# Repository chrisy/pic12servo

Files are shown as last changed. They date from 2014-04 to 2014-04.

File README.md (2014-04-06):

pic12servo
==========

This is a simple program to drive a hobby servo with a PIC12F683. It was
prepared using the MPLAB X IDE and the xc8 compiler.

The code sets up an analog-to-digital convertor input on pin 7 and
a PWM output on pin 5. It also sets up pulse outputs on pins 2 and 3
to allow us to measure the loop timing on an oscilloscope. The output
on pin 2 should be slow enough for a blinking LED.

The program loops reading the 10-bit value from the ADC and sets the
duty cycle of the PWM to a value derived from it.

The usable range for most servos requires a pulse length of between
about 1ms to 2ms (which represents the full range of motion for the
servo) with an overall pulse rate greater than 50Hz. This program
configures the PWM output to something close to 61Hz and calculates
the duty cycle value to correspond to a pulse of between about 1 and
2ms.

By hooking up a simple 10K ohm linear potentiometer wiper to pin 7,
with the pot ends across 0v and Vdd (the positive power to the PIC,
for example 5v) then the relative position of the pot will represent
the relative position of the servo motor across its full range.

Suitable hardware designs to facilitate this are in the hardware
directory.

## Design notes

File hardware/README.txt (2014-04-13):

The ServoDriver hardware
========================

servodriver.sch and servodriver.brd are Eagle diagrams.

servodriver.*.tap are G-Code CAM scripts generated using gcode-pcb.ulp.

Bill of Materials
=================

IC1		PIC12F683P (programmed, with 8 pin IC socket)
IC2		7805

R1		10K Pot
R2		Link
R3		620R
R4		620R

C1		0.1uF
C2		0.1uF
C3		0.1uF
C4		100uF electrolytic (25V or higher)
C5		10uF electrolytic (10V or higher)
C6		0.1uF

D1		1N4004

LED1	3mm red LED
LED2	3mm red LED

JP1		2-way Screw terminal
JP2		3-way 0.1" pitch pin header

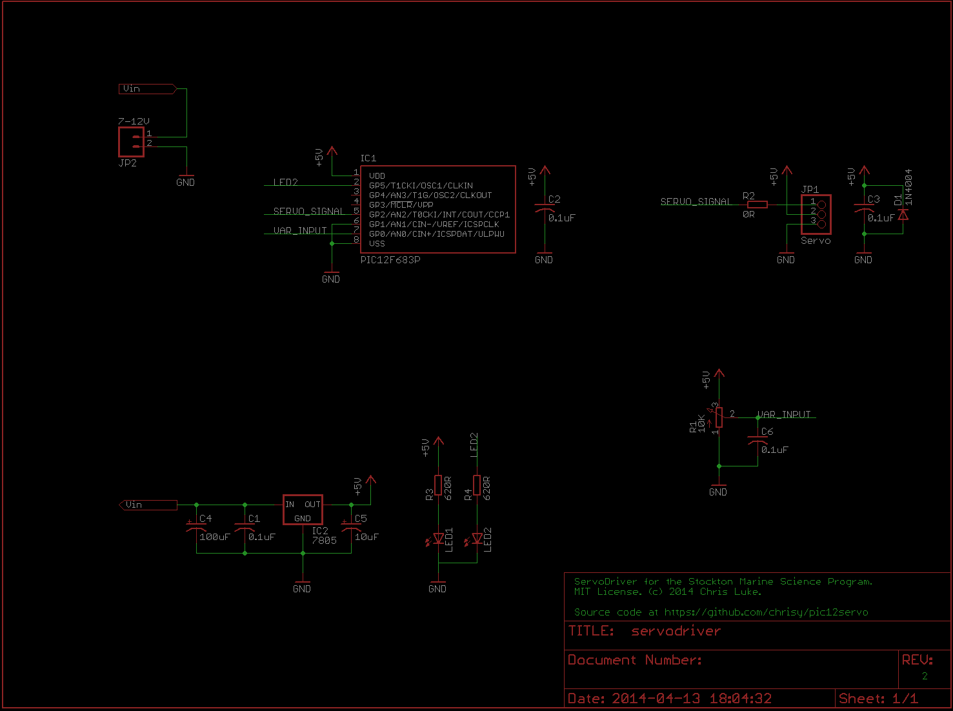
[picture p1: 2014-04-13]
hardware/servodriver-schematic.png

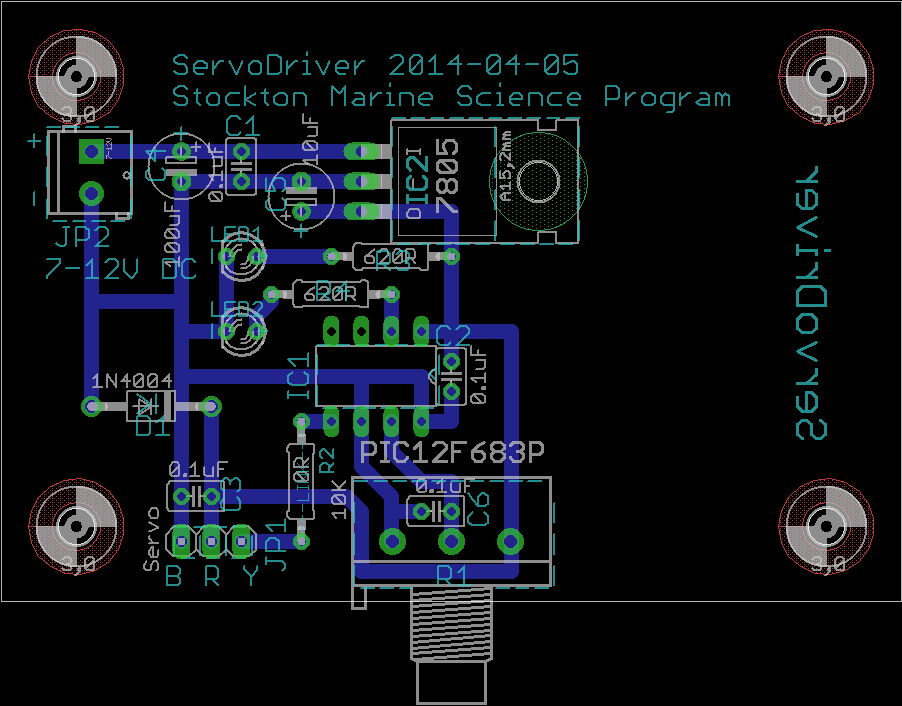
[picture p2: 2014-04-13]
hardware/servodriver-board.png

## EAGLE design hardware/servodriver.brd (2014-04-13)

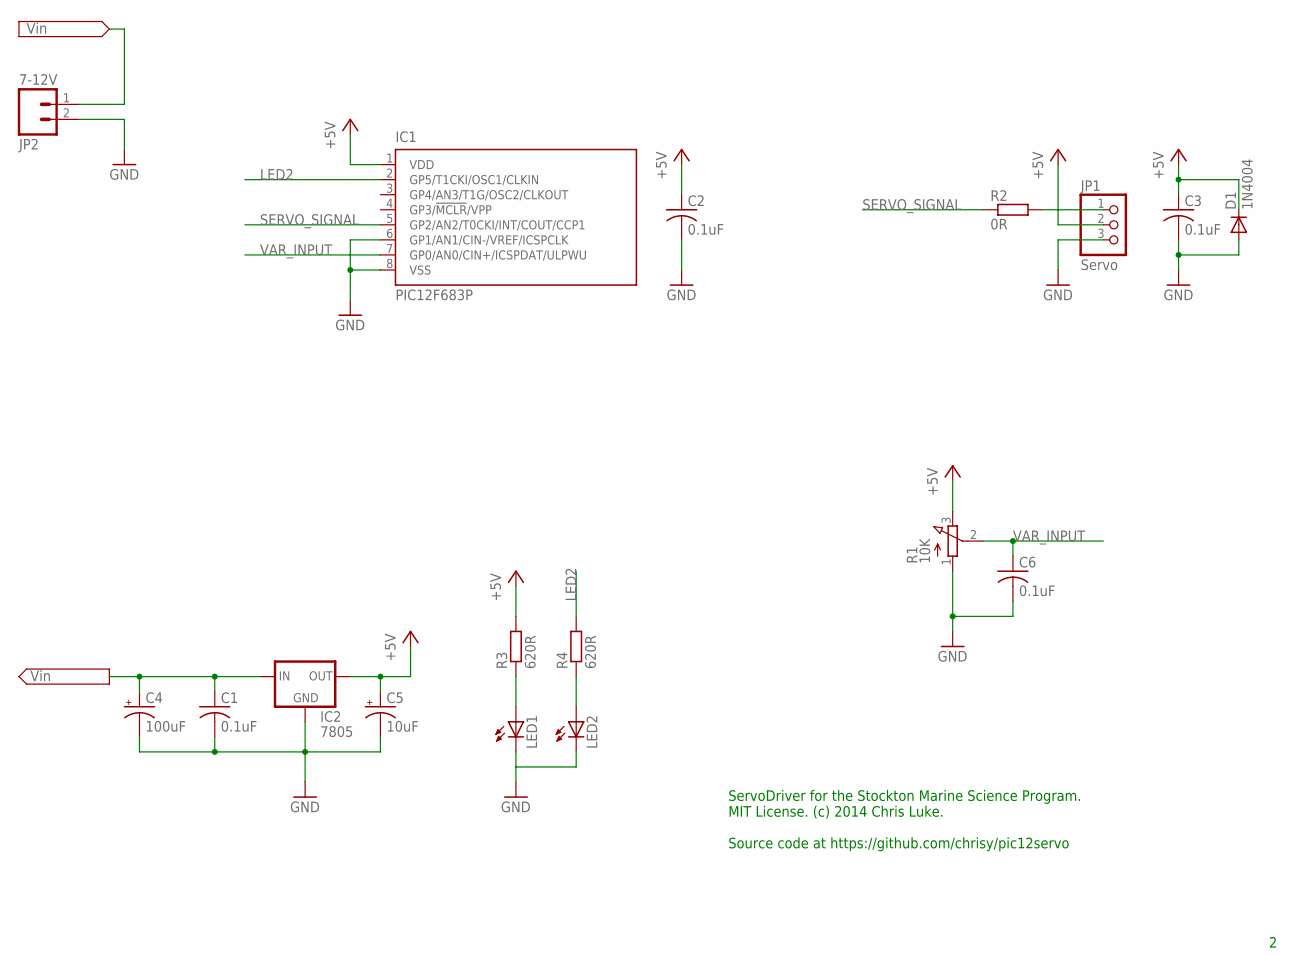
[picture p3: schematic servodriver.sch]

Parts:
C1, C2, C3, C6: 0.1uF; C025-025X050
C4: 100uF; E2,5-6
C5: 10uF; E2,5-6
D1: 1N4004; DO41-10
IC1: PIC12F683P; DIL8
IC2: 7805; 78XXL
JP1: Servo; 1X03
JP2: 7-12V; SCREWTERMINAL-3.5MM-2
LED1, LED2: LED3MM
R1: 10K; 3RP/1610N
R2: 0R; 0207/10
R3, R4: 620R; 0207/10

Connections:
+5V: C2.1, C3.1, C5.+, D1.C, IC1.1 (VDD), IC2.OUT, JP1.2, R1.3 (E), R3.2
GND: C1.2, C2.2, C3.2, C4.-, C5.-, C6.2, D1.A, IC1.6 (GP1/AN1/CIN-/VREF/ICSPCLK), IC1.8 (VSS), IC2.GND, JP1.3, JP2.2, LED1.K (C), LED2.K (C), R1.1 (A)
LED2: IC1.2 (GP5/T1CKI/OSC1/CLKIN), R4.2
unnamed: JP1.1, R2.2
unnamed: LED1.A, R3.1
unnamed: LED2.A, R4.1
SERVO_SIGNAL: IC1.5 (GP2/AN2/T0CKI/INT/COUT/CCP1), R2.1
VAR_INPUT: C6.1, IC1.7 (GP0/AN0/CIN+/ICSPDAT/ULPWU), R1.2 (S)
VIN: C1.1, C4.+, IC2.IN, JP2.1

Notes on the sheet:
ServoDriver for the Stockton Marine Science Program. MIT License. (c) 2014 Chris Luke. Source code at https://github.com/chrisy/pic12servo

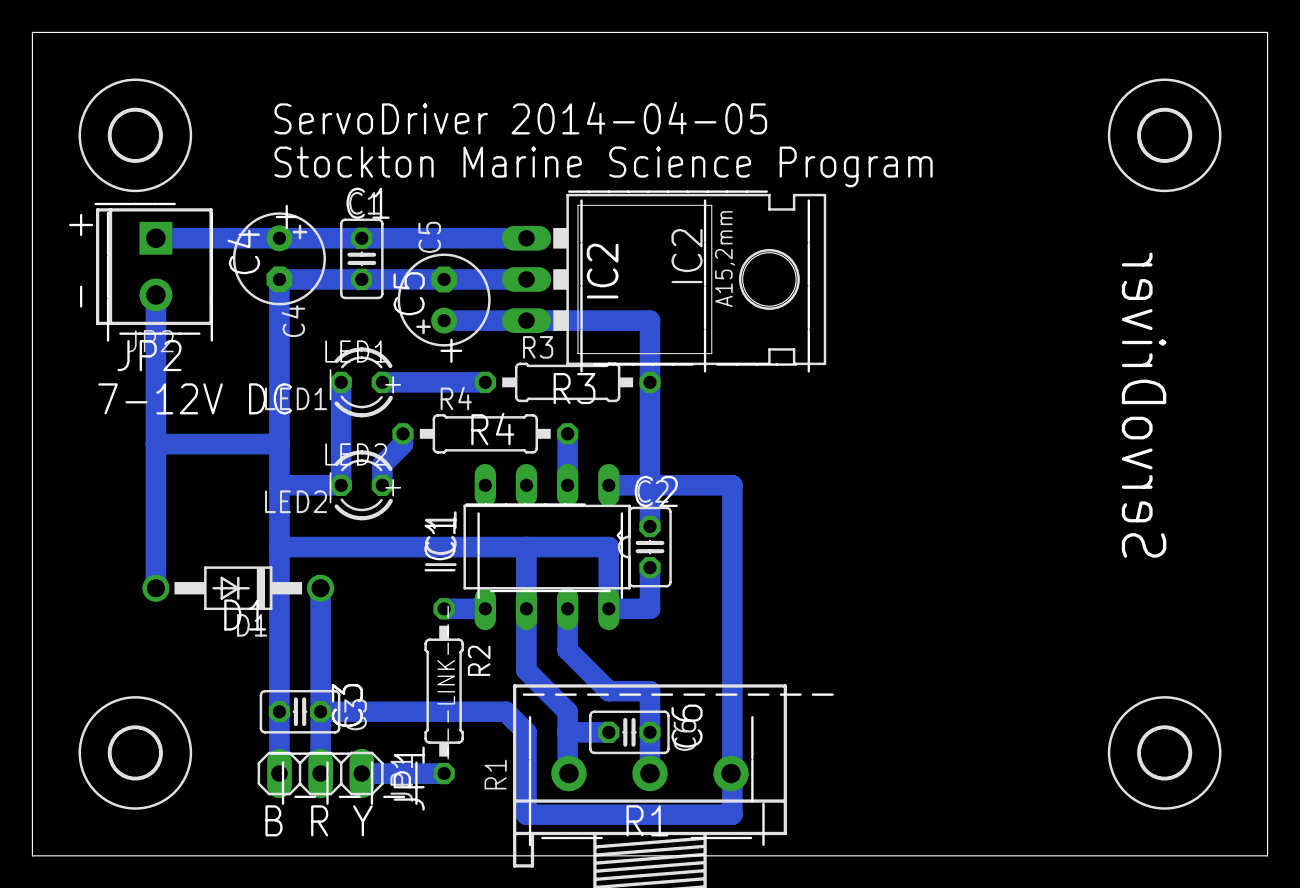
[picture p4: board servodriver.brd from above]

Board: 2 copper layers, 76.2 x 50.8 mm, 21 parts (0 on the bottom side), 9 nets.

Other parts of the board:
U$1, U$2, U$3, U$4: 3,0

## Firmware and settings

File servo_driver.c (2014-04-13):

/* 
 * File:    servo_driver.c
 * Author:  Chris Luke <chrisy@flirble.org>
 * License: MIT (c) 2014 Chris Luke
 */

#include "servo_driver.h"
#include "config.h"
#include <xc.h>

/* Initialize the hardware
 * GP0 is the analog input. Pin 7.
 * GP1 is unused though the board connects it to 0v for shielding. Pin 6.
 * GP2 is the PWM outut. Pin 5.
 * GP3 is unused. Pin 4.
 * GP4 is a loop-interval toggle output. Pin 3.
 * GP5 is an LED output. Pin 2.
 */
void init(void)
{
    OSCCONbits.IRCF = SET_IRCF; /* Set the clock speed */
    WDTCON = 0; /* Make sure watchdog is disabled */
    T1CON = 0; /* Make sure unused timers are off */

    di(); /* No need for interrupts */

    /* Setup the I/O */
    OPTION_REG = 0; /* Pullups via WPU */
    WPU = 0; /* No pullups to start with */
    GPIO = 0; /* Make sure all outputs are low */
    CMCON0 = 7; /* Disable the comparator */
    CMCON1 = 0;
    TRISIO = 0b001111; /* 4,5=out, 0,1,2,3=in */

    /* Setup ADC */
    ADCON0bits.ADFM = 1; /* right justified result */
    ADCON0bits.VCFG = 0; /* Use Vdd as Vref */
    ADCON0bits.CHS = 0; /* Select channel 0 */
    GO_DONE = 0; /* Make sure this is cleared */
    ANSELbits.ANS = 1; /* Only channel 0 is enabled */
    ANSELbits.ADCS = 0b111; /* Use internal RC oscilator */
    ADON = 1; /* Emable the ADC */

    /* Setup PWM */
    TRISIO2 = 1; /* Disable output on this pin for now */
    PR2 = SET_PR2; /* Set the PWM period (we aim for ~20ms, see config.h)  */
    CCP1CONbits.CCP1M = 0b1100; /* PWM mode */
    CCPR1L = 0; /* Reset PWM output to 0 */
    CCP1CONbits.DC1B = 0;

    /* Set the timer up for PWM operation */
    TMR2IF = 0; /* Make sure this is clear */
    T2CONbits.T2CKPS = 2; /* Timer 2 16:1 prescale */
    T2CONbits.TMR2ON = 1; /* TImer 2 on */

    while(!TMR2IF) { /* Wait for Timer 2 */
        continue;
    }
    TRISIO2 = 0; /* Set the pin as output */

    /* We have an LED on GP5 */
    TRISIO5 = 0;
    WPU5 = 0; /* Disable any pullup */

    /* And we will toggle GP4 for each iteration of the loop;
     * There's no real reason for this, other than we can
     * hook it up to an oscilloscope to time the loop
     * interval */
    TRISIO4 = 0;
    WPU4 = 0; /* Disable any pullup */

    /* Let it all settle */
    __delay_ms(10);
}

/*
 * Simple loop to read ADC value and set PWM duty
 * to the same value as a ratio of its range.
 */
int main(int argc, char **argv)
{
    unsigned int period, count;
    char o4, o5;

    /* Initialize the hardware */
    init();

    /* Calculate the PWM period from what we set PR2 to.
     * This will be ms*100, something like 1638 (61Hz) */
    period = (unsigned int)(
            ( ((float)SET_PR2) + 1.0 ) *
            4.0 *
            (1.0/(float)_XTAL_FREQ) *
            16.0 *
            1000.0 *
            100.0
    );

    /* This is the LED flashing loop counter */
    count = 0;

    for(;;) { /* Loop forver */
        unsigned int value, pulse;

        /* Trigger ADC. */
        GO_DONE = 1;

        /* Wait for conversion to complete. */
        while(GO_DONE) {
            continue;
        }

        /* Read ADC */
        value = ADRESH << 8;
        value |= ADRESL;

        /* Calculate the target pulse width in ms*100.
         * Useful range for most servos is 1ms to 2ms.
         * The values here give us a bit either side, just in case */
        pulse = 93 + (value / 9);

        /* Now adjust for the period of the timer.
         * We use floating point math for now, for accuracy.
         * Ideally we'd use integer math for speed, though we seem to
         * have enough cycles and memory for this. */
        pulse = (unsigned int)(1024.0 / ((float)period / (float)pulse));

        /* Set PWM */
        CCP1CONbits.DC1B = pulse & 0x03; /* Two LSB's */
        CCPR1L = (pulse >> 2) & 0xff; /* Eight MSB's */

        /* Wait a while - mostly to let ADC reset. */
        //__delay_us(100);

        /* Flash the LED */
        ++count;
        if(count > 10) {
            count = 0;
            o5 = o5 == 1 ? 0 : 1;
        }

        /* Toggle GP4 */
        o4 = o4 == 1 ? 0 : 1;

        /* We collate the GPIO output into a single call here
         * because of a well known 'read-modify-write' issue with
         * PIC chips without a separate latch output register. */
        GPIO = (o5 << 5) | (o4 << 4);
    }
}

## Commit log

2014-03-03 Simple PIC12 servo driver; reads an ADC value and sets the PWM to it
2014-03-14 Tweaks to make it work with most servos.
    In particular, it targets a specific pulse timing for the full
    range of the input signal. The useful range for most servos is
    about 1ms to 2ms of a pulse. The code calculates the desired
    pulse length and then converts this into the PWM timing
    necessary. This uses floating point for now, we may want to use
    integer math later for performance.
    We drop the processor clock to 1MHz and set the PWM counter such that
    we get something like a 16ms PWM period. This may be too quick for
    some servos but seems to work for this.
    We also setup some registers that were missing.
    [servo_driver.c]
2014-04-05 Add a blinky LED output!
2014-04-05 Add the hardware schematic and board
    [servodriver.brd, servodriver.sch]
2014-04-05 Add the CAM files
    [servodriver.brd, servodriver.sch]
2014-04-06 Update the hardware files
    - Latest CNC files
    - Add images of the schematic and board layout
2014-04-06 Update the README, refactor headers, add a workaround
    - Add pulsed outputs description to README
    - Describe servo pulse requirements in README
    - Normalize line endings since we've been using both Windows and MacOS
    - Refactor some items into servo_driver.h for general hygiene
    - Work around a potential semantic issue when assigning a bit field from the results of the ! operator
    [servo_driver.c]
2014-04-13 Update hardware details, including a BOM
    [servodriver.brd, servodriver.sch]
2014-04-13 Refactor the hardware init, make the LED work
    Refactor hardware initialization into an init() function and tweak
    various things to make the LED output work. Not least, account for
    some annoying read-modify-write semantics on this PIC (which doesn't have an independent output latch register).
    [servo_driver.c]

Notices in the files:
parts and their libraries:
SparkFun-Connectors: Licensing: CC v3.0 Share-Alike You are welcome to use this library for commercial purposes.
